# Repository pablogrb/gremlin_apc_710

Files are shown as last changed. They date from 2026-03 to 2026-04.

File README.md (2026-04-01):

# Gremlin APC 710

Hardware design repository for the Gremlin APC 710 project, containing:
- FreeCAD mechanical design files in [CAD](CAD)
- KiCAD electronics design files in [EDA](EDA)

## GitHub Repository

Project repository:
https://github.com/pablogrb/gremlin_apc_710

## Repository Structure

- [CAD](CAD)
  - FreeCAD source models (`.FCStd`)
  - Mechanical export files (for example `.step`)
- [EDA](EDA)
  - KiCAD schematic (`.kicad_sch`)
  - KiCAD PCB layout (`.kicad_pcb`)
  - KiCAD project files (`.kicad_pro`)

## Project Instructions

- CAD instructions: [docs/CAD_instructions.md](docs/CAD_instructions.md)
- EDA instructions: [docs/EDA_instructions.md](docs/EDA_instructions.md)

## Tooling

- Mechanical CAD: FreeCAD V1.1.0
- Electronic design: KiCAD V9.0.6

## Version Control Notes

This repository is configured to ignore temporary and machine-local artifacts generated by FreeCAD, KiCAD, and macOS (for example backup files, lock files, cache files, and `.DS_Store`).

## Font Licenses

Fonts used by this project are documented with folder-local license notes:

- [CAD/TTF/LICENSE.txt](CAD/TTF/LICENSE.txt)
- [EDA/TTF/LICENSE.txt](EDA/TTF/LICENSE.txt)

Current tracked font files include:

- CAD/TTF/DejaVuSansCondensed-Bold.ttf
- EDA/TTF/bamf.ttf

Important licensing note:
The Bamf font license (see [EDA/TTF/LICENSE.txt](EDA/TTF/LICENSE.txt)) states free use for non-commercial use and requires separate terms for commercial use.

## License

This project is licensed under the Creative Commons Attribution-NonCommercial 3.0 license.

See [LICENSE.md](LICENSE.md) for the dedicated license file.

License text and details:
https://creativecommons.org/licenses/by-nc/3.0/

Unless otherwise noted in specific files or directories, project content is distributed under this license.

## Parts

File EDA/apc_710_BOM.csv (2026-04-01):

Reference | Qty | Value | DNP | Exclude from BOM | Exclude from Board | Footprint | Datasheet
CONN_D0,CONN_D1 | 2 | Conn_02x13_Odd_Even |  |  |  | Connector_IDC:IDC-Header_2x13_P2.54mm_Vertical | ~
D_ALT1,D_AP1,D_APR1,D_BANK1,D_BC1,D_FLC1,D_HDG1,D_NAV1,D_SPD1,D_VNV1,D_VS1,D_XFR_L1,D_XFR_R1,D_YD1 | 14 | LED |  |  |  | LED_THT:LED_Rectangular_W3.0mm_H2.0mm | ~
RE_ALTS1,RE_CRS1,RE_CRS2,RE_HDG1,RE_UPDN1 | 5 | RotaryEncoder_Switch |  |  |  | easyeda2kicad:SW-TH_PEC11H-4020F-S0016 | ~
R_ALT1,R_AP1,R_APR1,R_BANK1,R_BC1,R_FLC1,R_HDG1,R_NAV1,R_SPD1,R_VNV1,R_VS1,R_XFR_L1,R_XFR_R1,R_YD1 | 14 | 220Ω |  |  |  | Resistor_THT:R_Axial_DIN0207_L6.3mm_D2.5mm_P7.62mm_Horizontal | ~
SW_ALT1,SW_AP1,SW_APR1,SW_BANK1,SW_BC1,SW_FD1,SW_FLC1,SW_HDG1,SW_NAV1,SW_SPD1,SW_VNV1,SW_VS1,SW_XFR1,SW_YD1 | 14 | SW_Push |  |  |  | Button_Switch_THT:SW_PUSH_6mm_H5mm | ~

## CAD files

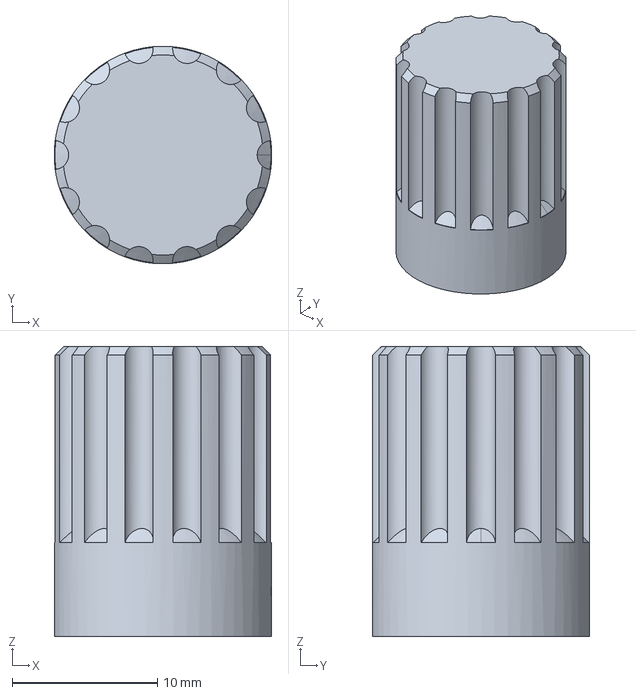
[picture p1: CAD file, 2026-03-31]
CAD/alt_knob.FCStd
15.0 x 15.0 x 20.0 mm

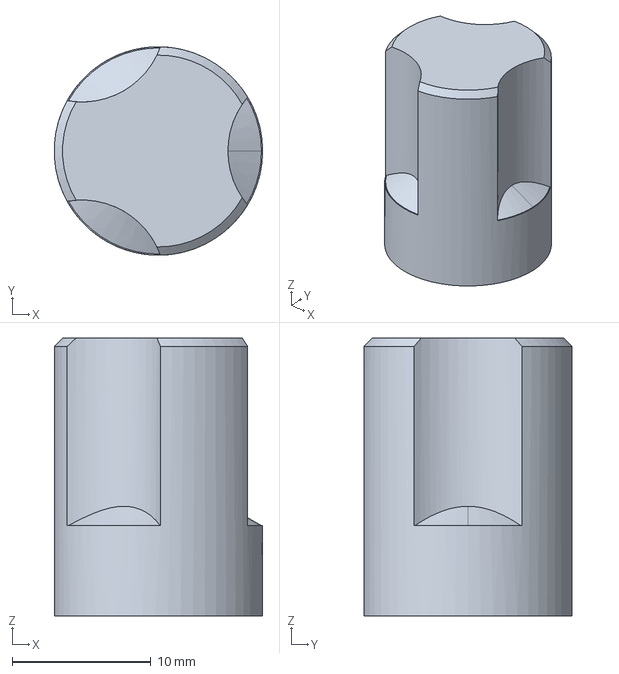
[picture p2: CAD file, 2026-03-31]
CAD/hdg_knob.FCStd
15.0 x 15.0 x 20.0 mm

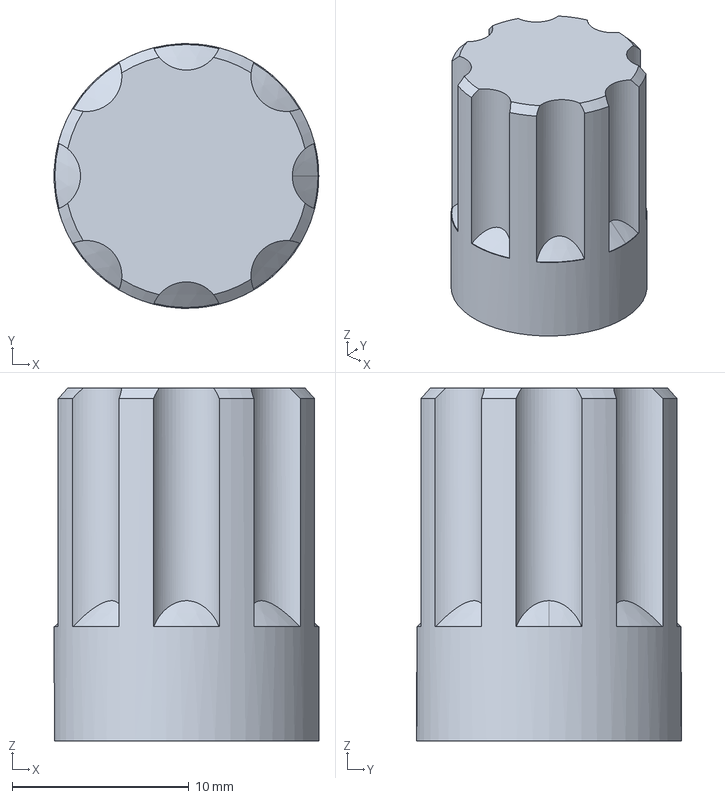
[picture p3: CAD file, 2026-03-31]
CAD/crs_knob.FCStd
15.0 x 15.0 x 20.0 mm

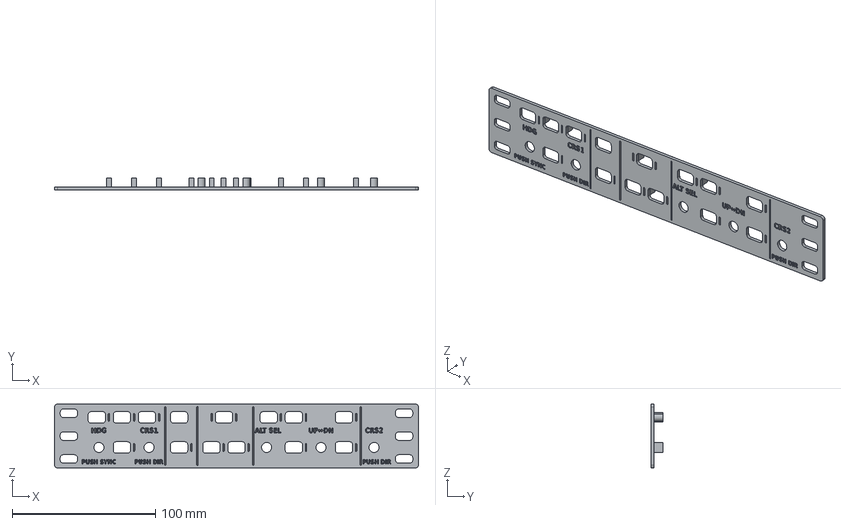
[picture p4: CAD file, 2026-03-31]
CAD/gremlin_apc_710_faceplate.step
254.0 x 8.20 x 44.5 mm
labels
face_plate

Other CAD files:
CAD/att_knob.FCStd
CAD/gremlin_apc_710_faceplate.FCStd

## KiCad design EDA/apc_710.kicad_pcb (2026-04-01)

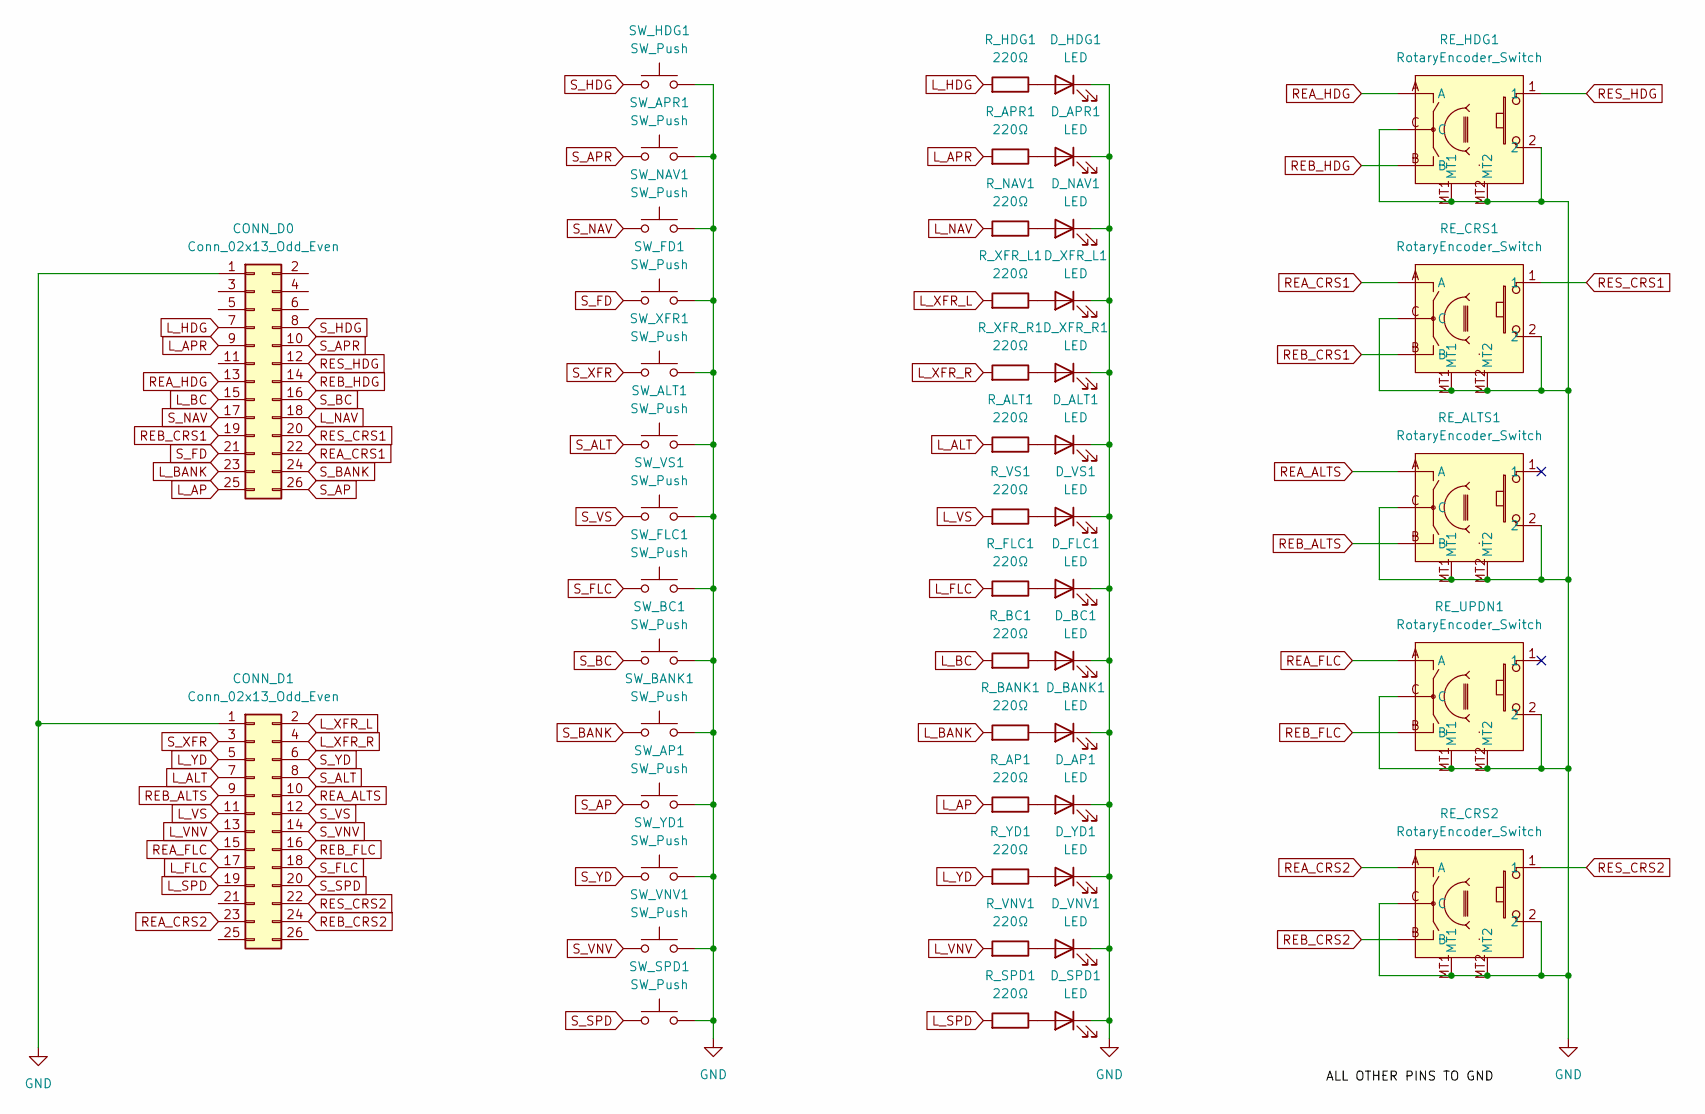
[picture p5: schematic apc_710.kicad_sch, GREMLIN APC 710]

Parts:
CONN_D0, CONN_D1: Conn_02x13_Odd_Even; IDC-Header_2x13_P2.54mm_Vertical
D_ALT1: LED; LED_Rectangular_W3.0mm_H2.0mm
D_AP1: LED; LED_Rectangular_W3.0mm_H2.0mm
D_APR1: LED; LED_Rectangular_W3.0mm_H2.0mm
D_BANK1: LED; LED_Rectangular_W3.0mm_H2.0mm
D_BC1: LED; LED_Rectangular_W3.0mm_H2.0mm
D_FLC1: LED; LED_Rectangular_W3.0mm_H2.0mm
D_HDG1: LED; LED_Rectangular_W3.0mm_H2.0mm
D_NAV1: LED; LED_Rectangular_W3.0mm_H2.0mm
D_SPD1: LED; LED_Rectangular_W3.0mm_H2.0mm
D_VNV1: LED; LED_Rectangular_W3.0mm_H2.0mm
D_VS1: LED; LED_Rectangular_W3.0mm_H2.0mm
D_XFR_L1: LED; LED_Rectangular_W3.0mm_H2.0mm
D_XFR_R1: LED; LED_Rectangular_W3.0mm_H2.0mm
D_YD1: LED; LED_Rectangular_W3.0mm_H2.0mm
RE_ALTS1: RotaryEncoder_Switch; SW-TH_PEC11H-4020F-S0016; LCSC Part C22402656
RE_CRS1, RE_CRS2: RotaryEncoder_Switch; SW-TH_PEC11H-4020F-S0016; LCSC Part C22402656
RE_HDG1: RotaryEncoder_Switch; SW-TH_PEC11H-4020F-S0016; LCSC Part C22402656
RE_UPDN1: RotaryEncoder_Switch; SW-TH_PEC11H-4020F-S0016; LCSC Part C22402656
R_ALT1: 220Ω; R_Axial_DIN0207_L6.3mm_D2.5mm_P7.62mm_Horizontal
R_AP1: 220Ω; R_Axial_DIN0207_L6.3mm_D2.5mm_P7.62mm_Horizontal
R_APR1: 220Ω; R_Axial_DIN0207_L6.3mm_D2.5mm_P7.62mm_Horizontal
R_BANK1: 220Ω; R_Axial_DIN0207_L6.3mm_D2.5mm_P7.62mm_Horizontal
R_BC1: 220Ω; R_Axial_DIN0207_L6.3mm_D2.5mm_P7.62mm_Horizontal
R_FLC1: 220Ω; R_Axial_DIN0207_L6.3mm_D2.5mm_P7.62mm_Horizontal
R_HDG1: 220Ω; R_Axial_DIN0207_L6.3mm_D2.5mm_P7.62mm_Horizontal
R_NAV1: 220Ω; R_Axial_DIN0207_L6.3mm_D2.5mm_P7.62mm_Horizontal
R_SPD1: 220Ω; R_Axial_DIN0207_L6.3mm_D2.5mm_P7.62mm_Horizontal
R_VNV1: 220Ω; R_Axial_DIN0207_L6.3mm_D2.5mm_P7.62mm_Horizontal
R_VS1: 220Ω; R_Axial_DIN0207_L6.3mm_D2.5mm_P7.62mm_Horizontal
R_XFR_L1: 220Ω; R_Axial_DIN0207_L6.3mm_D2.5mm_P7.62mm_Horizontal
R_XFR_R1: 220Ω; R_Axial_DIN0207_L6.3mm_D2.5mm_P7.62mm_Horizontal
R_YD1: 220Ω; R_Axial_DIN0207_L6.3mm_D2.5mm_P7.62mm_Horizontal
SW_ALT1: SW_Push; SW_PUSH_6mm_H5mm
SW_AP1: SW_Push; SW_PUSH_6mm_H5mm
SW_APR1: SW_Push; SW_PUSH_6mm_H5mm
SW_BANK1: SW_Push; SW_PUSH_6mm_H5mm
SW_BC1: SW_Push; SW_PUSH_6mm_H5mm
SW_FD1: SW_Push; SW_PUSH_6mm_H5mm
SW_FLC1: SW_Push; SW_PUSH_6mm_H5mm
SW_HDG1: SW_Push; SW_PUSH_6mm_H5mm
SW_NAV1: SW_Push; SW_PUSH_6mm_H5mm
SW_SPD1: SW_Push; SW_PUSH_6mm_H5mm
SW_VNV1: SW_Push; SW_PUSH_6mm_H5mm
SW_VS1: SW_Push; SW_PUSH_6mm_H5mm
SW_XFR1: SW_Push; SW_PUSH_6mm_H5mm
SW_YD1: SW_Push; SW_PUSH_6mm_H5mm

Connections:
GND: CONN_D0.1, CONN_D1.1, D_ALT1.1 (K), D_AP1.1 (K), D_APR1.1 (K), D_BANK1.1 (K), D_BC1.1 (K), D_FLC1.1 (K), D_HDG1.1 (K), D_NAV1.1 (K), D_SPD1.1 (K), D_VNV1.1 (K), D_VS1.1 (K), D_XFR_L1.1 (K), D_XFR_R1.1 (K), D_YD1.1 (K), RE_ALTS1.2, RE_ALTS1.C, RE_ALTS1.MT1, RE_ALTS1.MT2, RE_CRS1.2, RE_CRS1.C, RE_CRS1.MT1, RE_CRS1.MT2, RE_CRS2.2, RE_CRS2.C, RE_CRS2.MT1, RE_CRS2.MT2, RE_HDG1.2, RE_HDG1.C, RE_HDG1.MT1, RE_HDG1.MT2, RE_UPDN1.2, RE_UPDN1.C, RE_UPDN1.MT1, RE_UPDN1.MT2, SW_ALT1.2, SW_AP1.2, SW_APR1.2, SW_BANK1.2, SW_BC1.2, SW_FD1.2, SW_FLC1.2, SW_HDG1.2, SW_NAV1.2, SW_SPD1.2, SW_VNV1.2, SW_VS1.2, SW_XFR1.2, SW_YD1.2
L_ALT: CONN_D1.7, R_ALT1.2
L_AP: CONN_D0.25, R_AP1.2
L_APR: CONN_D0.9, R_APR1.2
L_BANK: CONN_D0.23, R_BANK1.2
L_BC: CONN_D0.15, R_BC1.2
L_FLC: CONN_D1.17, R_FLC1.2
L_HDG: CONN_D0.7, R_HDG1.2
L_NAV: CONN_D0.18, R_NAV1.2
L_SPD: CONN_D1.19, R_SPD1.2
L_VNV: CONN_D1.13, R_VNV1.2
L_VS: CONN_D1.11, R_VS1.2
L_XFR_L: CONN_D1.2, R_XFR_L1.2
L_XFR_R: CONN_D1.4, R_XFR_R1.2
L_YD: CONN_D1.5, R_YD1.2
unnamed: D_ALT1.2 (A), R_ALT1.1
unnamed: D_AP1.2 (A), R_AP1.1
unnamed: D_APR1.2 (A), R_APR1.1
unnamed: D_BANK1.2 (A), R_BANK1.1
unnamed: D_BC1.2 (A), R_BC1.1
unnamed: D_FLC1.2 (A), R_FLC1.1
unnamed: D_HDG1.2 (A), R_HDG1.1
unnamed: D_NAV1.2 (A), R_NAV1.1
unnamed: D_SPD1.2 (A), R_SPD1.1
unnamed: D_VNV1.2 (A), R_VNV1.1
unnamed: D_VS1.2 (A), R_VS1.1
unnamed: D_XFR_L1.2 (A), R_XFR_L1.1
unnamed: D_XFR_R1.2 (A), R_XFR_R1.1
unnamed: D_YD1.2 (A), R_YD1.1
REA_ALTS: CONN_D1.10, RE_ALTS1.A
REA_CRS1: CONN_D0.22, RE_CRS1.A
REA_CRS2: CONN_D1.23, RE_CRS2.A
REA_FLC: CONN_D1.15, RE_UPDN1.A
REA_HDG: CONN_D0.13, RE_HDG1.A
REB_ALTS: CONN_D1.9, RE_ALTS1.B
REB_CRS1: CONN_D0.19, RE_CRS1.B
REB_CRS2: CONN_D1.24, RE_CRS2.B
REB_FLC: CONN_D1.16, RE_UPDN1.B
REB_HDG: CONN_D0.14, RE_HDG1.B
RES_CRS1: CONN_D0.20, RE_CRS1.1
RES_CRS2: CONN_D1.22, RE_CRS2.1
RES_HDG: CONN_D0.12, RE_HDG1.1
S_ALT: CONN_D1.8, SW_ALT1.1
S_AP: CONN_D0.26, SW_AP1.1
S_APR: CONN_D0.10, SW_APR1.1
S_BANK: CONN_D0.24, SW_BANK1.1
S_BC: CONN_D0.16, SW_BC1.1
S_FD: CONN_D0.21, SW_FD1.1
S_FLC: CONN_D1.18, SW_FLC1.1
S_HDG: CONN_D0.8, SW_HDG1.1
S_NAV: CONN_D0.17, SW_NAV1.1
S_SPD: CONN_D1.20, SW_SPD1.1
S_VNV: CONN_D1.14, SW_VNV1.1
S_VS: CONN_D1.12, SW_VS1.1
S_XFR: CONN_D1.3, SW_XFR1.1
S_YD: CONN_D1.6, SW_YD1.1

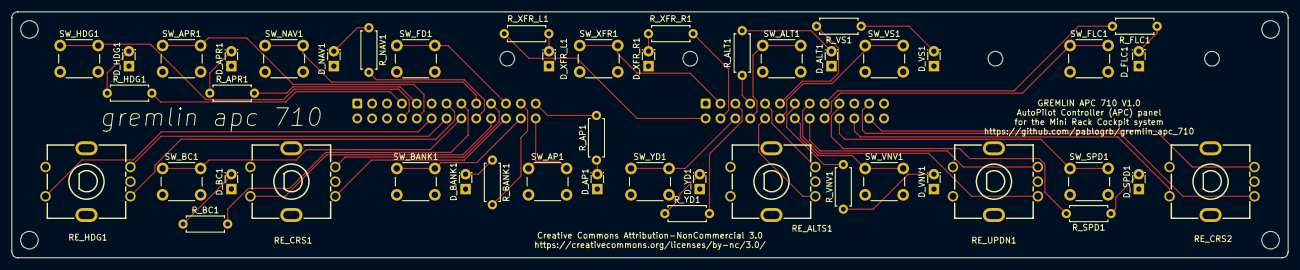
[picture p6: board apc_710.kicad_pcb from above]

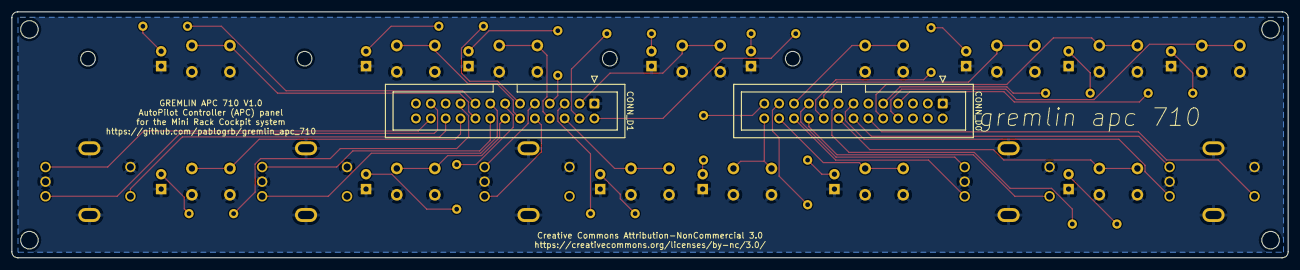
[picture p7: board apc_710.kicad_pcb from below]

Board: 2 copper layers, 218.0 x 42.0 mm, 49 parts (2 on the bottom side), 56 nets.

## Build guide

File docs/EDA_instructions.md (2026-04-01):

# Gremlin APC 710

## EDA Instructions

This document describes the electronics design files and a basic workflow for working with the APC 710 KiCAD project.

## Project Files

- KiCAD project file: [EDA/apc_710.kicad_pro](../EDA/apc_710.kicad_pro)
- Schematic: [EDA/apc_710.kicad_sch](../EDA/apc_710.kicad_sch)
- PCB layout: [EDA/apc_710.kicad_pcb](../EDA/apc_710.kicad_pcb)

## Bill Of Materials

| Qty | Value | Footprint | References |
| --- | --- | --- | --- |
| 2 | Conn_02x13_Odd_Even | Connector_IDC:IDC-Header_2x13_P2.54mm_Vertical | CONN_D0, CONN_D1 |
| 14 | LED | LED_THT:LED_Rectangular_W3.0mm_H2.0mm | D_ALT1, D_AP1, D_APR1, D_BANK1, D_BC1, D_FLC1, D_HDG1, D_NAV1, D_SPD1, D_VNV1, D_VS1, D_XFR_L1, D_XFR_R1, D_YD1 |
| 5 | RotaryEncoder_Switch | easyeda2kicad:SW-TH_PEC11H-4020F-S0016 | RE_ALTS1, RE_CRS1, RE_CRS2, RE_HDG1, RE_UPDN1 |
| 14 | 220Ω | Resistor_THT:R_Axial_DIN0207_L6.3mm_D2.5mm_P7.62mm_Horizontal | R_ALT1, R_AP1, R_APR1, R_BANK1, R_BC1, R_FLC1, R_HDG1, R_NAV1, R_SPD1, R_VNV1, R_VS1, R_XFR_L1, R_XFR_R1, R_YD1 |
| 14 | SW_Push | Button_Switch_THT:SW_PUSH_6mm_H5mm | SW_ALT1, SW_AP1, SW_APR1, SW_BANK1, SW_BC1, SW_FD1, SW_FLC1, SW_HDG1, SW_NAV1, SW_SPD1, SW_VNV1, SW_VS1, SW_XFR1, SW_YD1 |

## Assembly

All components are through hole and can be soldered with hobby-grade equipment. Note that the IDC-Header_2x13_P2.54mm_Vertical connectors can be replaced by your choice of 2.54 mm pitch headers. The LED_Rectangular_W3.0mm_H2.0mm can be up to 6 mm in height, 4 mm is recommended. The SW-TH_PEC11H-4020F-S0016 are Bourns PEC11H-4020F-S0016 but generic equivalents can be easily sourced as EC11 D-shaft switch encoders.

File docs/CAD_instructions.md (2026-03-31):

# Gremlin APC 710

## Faceplate

| Front View | Rear View |
| --- | --- |
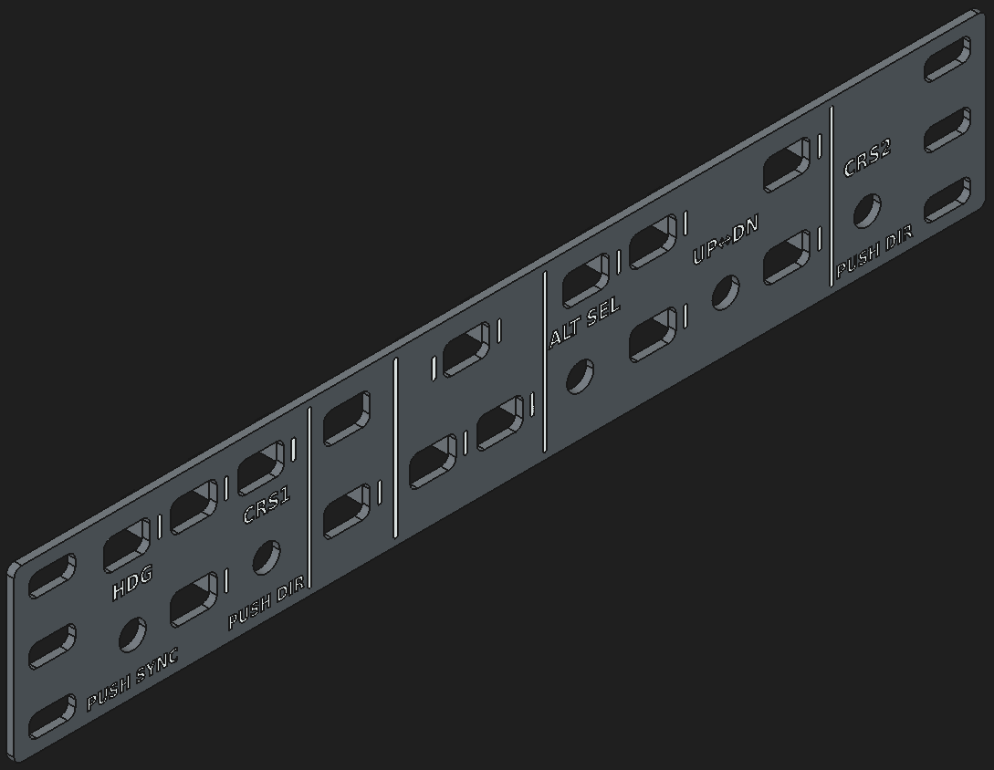
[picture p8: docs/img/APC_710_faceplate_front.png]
APC 710 faceplate front view
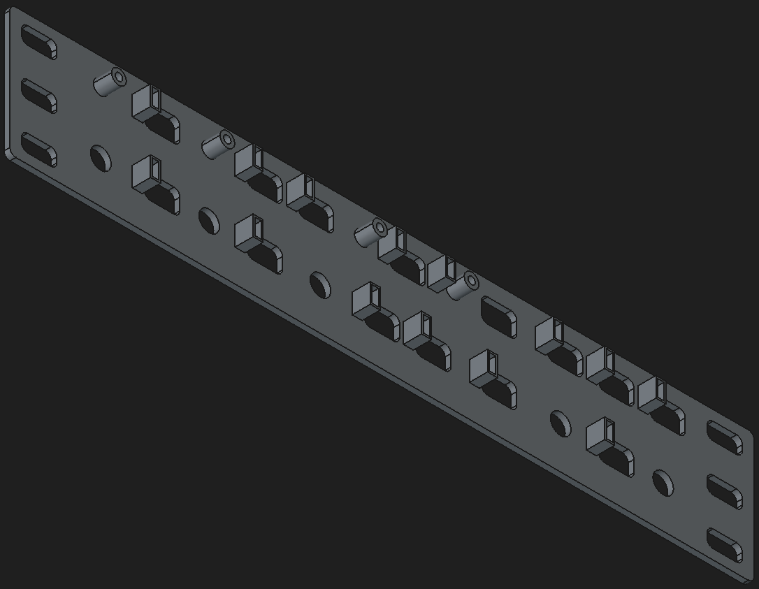
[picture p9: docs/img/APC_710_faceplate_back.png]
APC 710 faceplate rear view
|  |  |
| Front of the APC 710 faceplate model showing control and mounting geometry. | Rear of the APC 710 faceplate model showing backside structure and clearances. |

The FreeCAD 3D model for the APC 710 faceplate is contained in [CAD/gremlin_apc_710_faceplate.FCStd](../CAD/gremlin_apc_710_faceplate.FCStd). It is built as a parametric part based in a variable set and can serve as the base for the creation of similar autopilot instruments.

A 3D printer-ready STEP file is provided at [CAD/gremlin_apc_710_faceplate.step](../CAD/gremlin_apc_710_faceplate.step). The faceplate fits completely in a 220 x 220 mm print bed and can be split in a suitable slicer to fit in smaller print areas. No supports are needed.

The Step file is set up for multi-material printing, but in such a way that it can be printed in mono-material printers. The coloured labels are 0.2 mm thick, which can be used as the layer height. Print the labels first, excecute a manual filament change and continue the print. For some printers, this procedure can be semi-automated in the slicer.

## Knobs

| ALT Knob | CRS Knob |
| --- | --- |
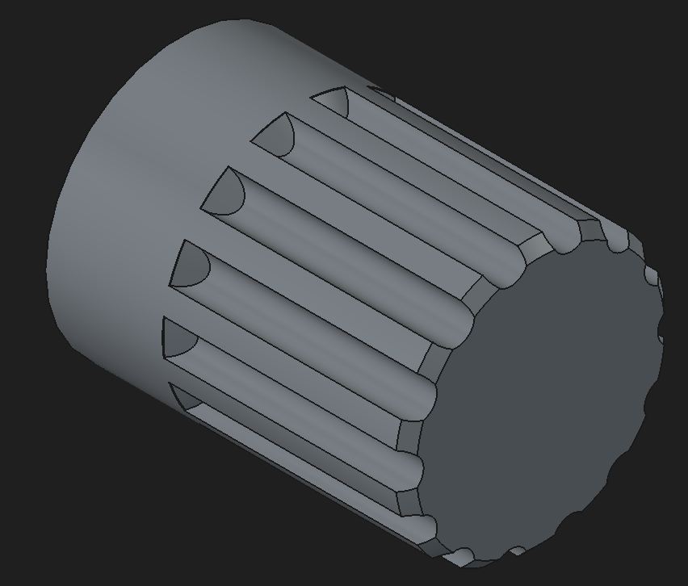
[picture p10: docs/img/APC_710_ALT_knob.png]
APC 710 ALT knob
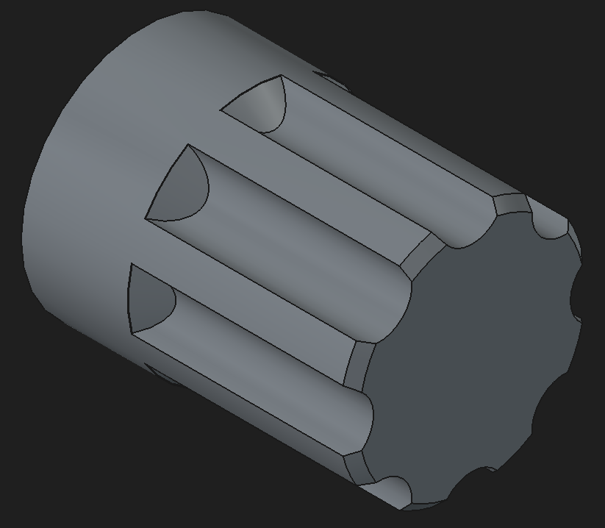
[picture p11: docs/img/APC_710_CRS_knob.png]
APC 710 CRS knob
|  |  |
| ALT selector knob geometry. Source: [CAD/alt_knob.FCStd](../CAD/alt_knob.FCStd). | CRS selector knob geometry. Source: [CAD/crs_knob.FCStd](../CAD/crs_knob.FCStd). |

| HDG Knob | UP/DN Knob |
| --- | --- |
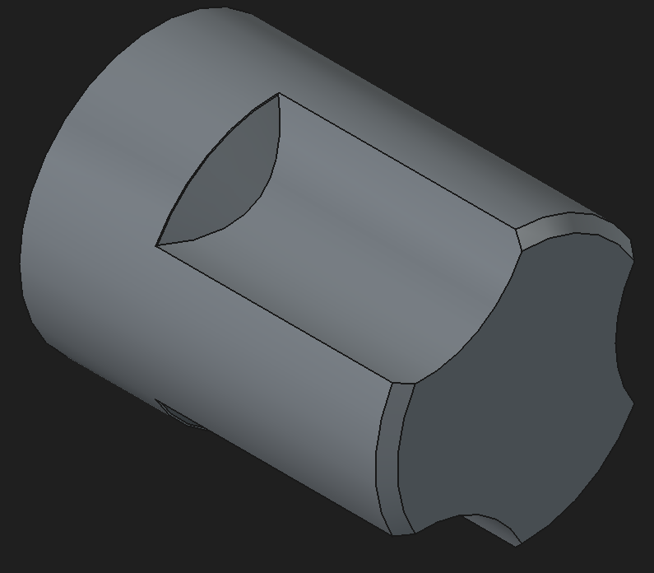
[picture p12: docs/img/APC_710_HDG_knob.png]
APC 710 HDG knob
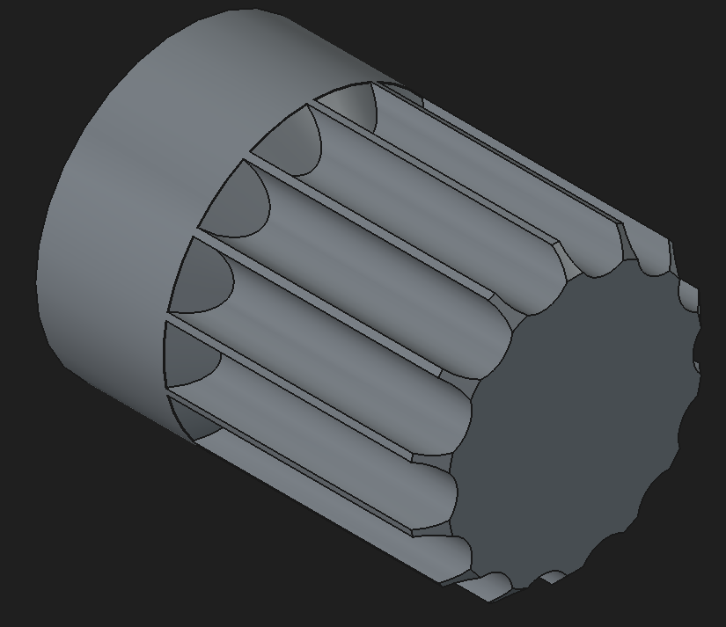
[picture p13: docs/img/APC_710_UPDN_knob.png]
APC 710 UP/DN knob
|  |  |
| HDG selector knob geometry. Source: [CAD/hdg_knob.FCStd](../CAD/hdg_knob.FCStd). | UP/DN knob geometry. Source: [CAD/att_knob.FCStd](../CAD/att_knob.FCStd). |

4 different knob designs are used to allow for the tactile identification of the different knob functions. The knobs are designed to be printed with the top of the knob against the print plate and the hole side facing up, this allows printing with no supports. The inner diameter of the mounting hole has been sized for a sliding fit in the encoders, accounting for PLA shrinking. Edit according to your material of choice.

## Buttons

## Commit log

2026-03-31 Initial commit
    CAD and EDA models
    Base readme file
    [alt_knob.FCStd, att_knob.FCStd, crs_knob.FCStd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]
2026-03-31 Updated FreeCAD files to FreeCAD V1.1
    [alt_knob.FCStd, att_knob.FCStd, crs_knob.FCStd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]
2026-03-31 Update README and add CAD instructions with images for APC 710 faceplate and knobs
2026-04-01 renamed EDA files
    [apc_710.kicad_pcb, apc_710.kicad_sch]
2026-04-01 GitHub info
    * added exception for schematic lockfiles
    * added github link to readme
    * added github link to pcb, pcb diagram, and schematic diagram
    [apc_710.kicad_pcb, apc_710.kicad_sch]
2026-04-01 EDA documentation and BOM
    [apc_710_BOM.csv]
2026-04-01 Add KiCAD generated files and build artifacts to .gitignore
